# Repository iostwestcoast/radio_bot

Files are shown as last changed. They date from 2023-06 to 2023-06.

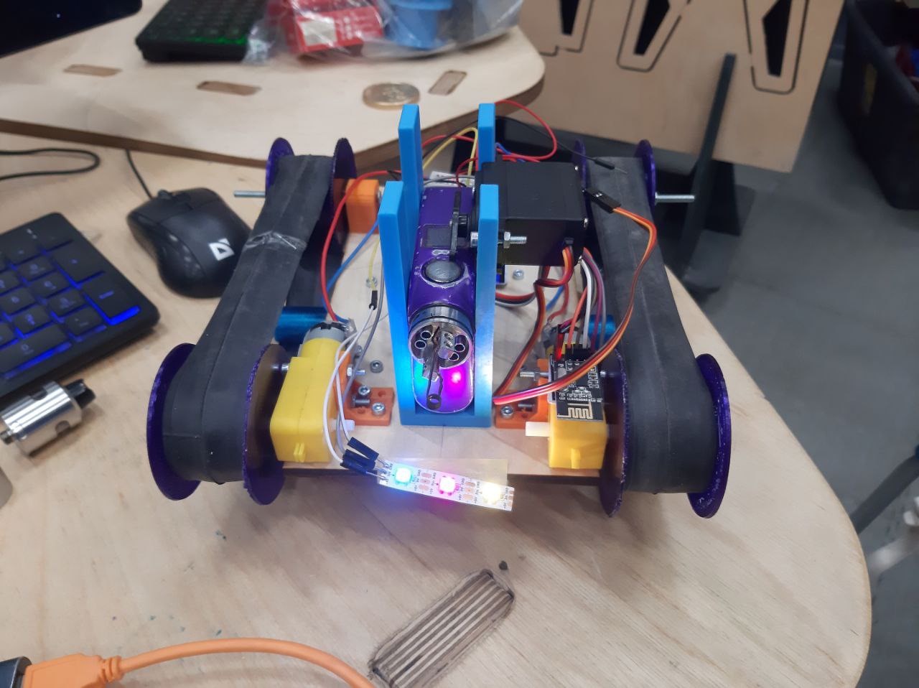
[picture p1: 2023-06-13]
Photos & Videoes/photo_2023-06-12_13-10-41.jpg

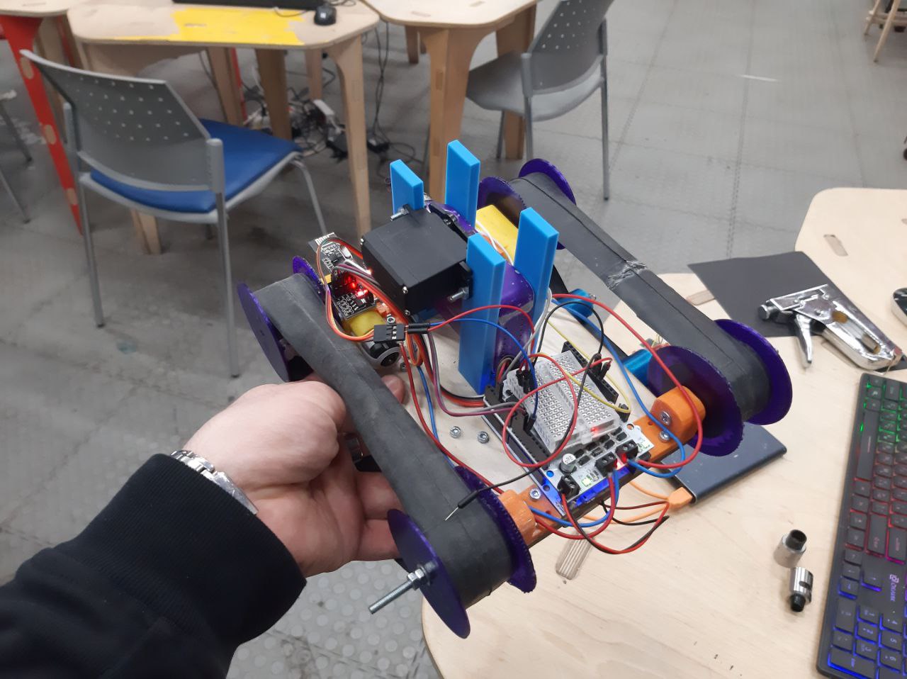
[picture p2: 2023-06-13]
Photos & Videoes/photo_2023-06-12_13-10-38.jpg

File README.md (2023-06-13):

# Radio Bot

Remote controlled bot based on an Arduino using a radio module

The final look of the bot:



The final view of the control panel:



https://github.com/iostwestcoast/radio_bot/assets/114690482/ab062ac3-bc5f-469a-a076-65d38420400c

Сomponents:

- NRF

- NRF+

- Motor Shield

- Arduino Leonardo/Amperka Iskra Neo

- Arduino Pro Micro

- x2 18650

- x2 DC motor

- x2 joystick

- RGB LED strip

- potentiometer

- x2 bradboard

- powerbank

- vape mod

- servo 360

The bot was created to pass a certain obstacle course and unfortunately for technical reasons did not meet expectations

In the end, 1/4 of the obstacle was passed and it took 9.45 minutes to complete the entire course



1. Control panel code:
```C++
#include <SPI.h>
#include <nRF24L01.h>
#include <RF24.h>

RF24 radio(8, 10);
int data[3];

#define PIN_VRX A2
#define PIN_VRY A3

void setup() {
  Serial.begin(9600);

  radio.begin();
  radio.setChannel(1);
  radio.setDataRate(RF24_1MBPS);
  radio.setPALevel(RF24_PA_HIGH);
  radio.openWritingPipe(0x2234567890LL);
  radio.stopListening();

  pinMode(A1, INPUT);
}

void loop() {
  int potval = analogRead(A1);

  radio.write(&data, sizeof(data));
  delay(50);

  Serial.println(potval);
     
  int valX = analogRead(PIN_VRX);
  int valY = analogRead(PIN_VRY);

  Serial.print("X = ");
  Serial.println(analogRead(PIN_VRX));

  Serial.print("Y = ");
  Serial.println(analogRead(PIN_VRY));

  data[0] = potval;
  data[1] = valX;
  data[2] = valY;
}
```

2. Bot code:
```C++
#include <SPI.h>
#include <nRF24L01.h>
#include <RF24.h>
#include <Servo.h>

Servo servo;

#define servoPin 11
int data[3];

RF24 radio(9, 10);

#define SPEED_1      5 
#define DIR_1        4
 
#define SPEED_2      6
#define DIR_2        7

#define LED_PIN 3
#define LED_NUM 3
#include "FastLED.h"
CRGB leds[LED_NUM];
byte counter;

void setup(){
  Serial.begin(9600);

  radio.begin();
  radio.setChannel(1);
  radio.setDataRate(RF24_1MBPS);
  radio.setPALevel(RF24_PA_HIGH);
  radio.openReadingPipe(0, 0x2234567890LL);
  radio.startListening();

  servo.attach(servoPin);

  for (int i = 4; i < 8; i++) {     
  pinMode(i, OUTPUT);

  FastLED.addLeds<WS2812, LED_PIN, GRB>(leds, LED_NUM);
  FastLED.setBrightness(200);
  }
}

void loop(){
  if (radio.available()){
    radio.read(&data, sizeof(data));
    Serial.println(String(data[0]) + "; " + String(data[1]) + "; " + String(data[2]));
  
  int potVal = data[0];
  servo.write(map(potVal, 0, 1023, 0, 180));

  delay(50);
  
  int valX = data[1];
  int valY = data[2];

  if (valX < 112) {
   digitalWrite(DIR_1, LOW);
   analogWrite(SPEED_1, 255);

   digitalWrite(DIR_2, HIGH);
   analogWrite(SPEED_2, 255);
  }
  else if (valX > 912) {
   digitalWrite(DIR_1, HIGH);
   analogWrite(SPEED_1, 255);

   digitalWrite(DIR_2, LOW);
   analogWrite(SPEED_2, 255);
  }
  else if (valY < 112) {
   digitalWrite(DIR_1, LOW);
   analogWrite(SPEED_1, 255);

   digitalWrite(DIR_2, LOW);
   analogWrite(SPEED_2, 255);
  }
  else if (valY > 912) {
   digitalWrite(DIR_1, HIGH);
   analogWrite(SPEED_1, 255);

   digitalWrite(DIR_2, HIGH);
   analogWrite(SPEED_2, 255);
  }
  
  else if (112 < valX < 912){
   digitalWrite(DIR_1, HIGH);
   analogWrite(SPEED_1, 0);

   digitalWrite(DIR_2, HIGH);
   analogWrite(SPEED_2, 0);
  }
  else if (112 < valY < 912){
   digitalWrite(DIR_1, HIGH);
   analogWrite(SPEED_1, 0);

   digitalWrite(DIR_2, HIGH);
   analogWrite(SPEED_2, 0);
  }
  }

  for (int i = 0; i < LED_NUM; i++) {
    leds[i].setHue(counter + i * 255 / LED_NUM);
  }
  counter++;
  FastLED.show();
}
```

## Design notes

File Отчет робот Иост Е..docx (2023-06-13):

МИНИСТЕРСТВО ОБРАЗОВАНИЯ И НАУКИ РОССИЙСКОЙ ФЕДЕРАЦИИ

ФЕДЕРАЛЬНОЕ ГОСУДАРСТВЕННОЕ АВТОНОМНОЕ УЧРЕЖДЕНИЕ ВЫСШЕГО ОБРАЗОВАНИЯ

«Национальный исследовательский технологический

университет «МИСиС»

ИНСТИТУТ ЭКОТЕХНОЛОГИЙ И ИНЖИНИРИНГА

КАФЕДРА МЕТАЛЛОВЕДЕНИЕ ЦВЕТНЫХ МЕТАЛЛОВ

НАПРАВЛЕНИЕ 15.04.02 Технологические машины и оборудование

Практика цифрового производства

на тему: “Робот на радиоуправлении”

Студент: Иост Е.С.

Группа: МТМО-22-3

Проверил: Тавитов А.Г.

Москва 2023

Введение

Цель проекта: построить робота без колес с дистанционным управлением для прохождения полосы препятствий.

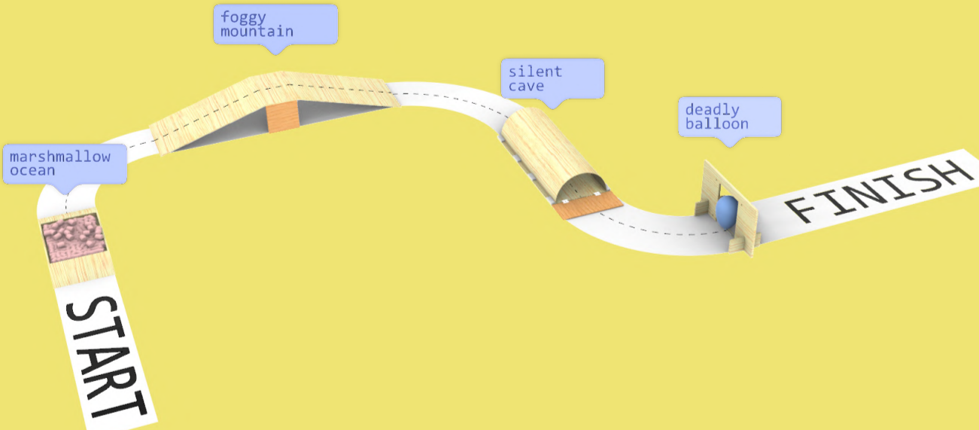
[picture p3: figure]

Рисунок 1 – Полоса препятствий

Компоненты, которые использовались в данном проекте:

- NRF

- NRF+

- Motor Shield

- Arduino Leonardo/Amperka Iskra Neo

- Arduino Pro Micro

- x2 18650

- x2 DC motor

- x2 joystick

- RGB LED strip

- potentiometer

- x2 bradboard

- powerbank

- vape mod

- servo 360

Скетчинг, эскизирование

Для начала работы было принято решение заскетчить все возможные варианты рабочих механизмов и расположения компонентов. Были сняты все размеры основных компонентов и важных узлов.

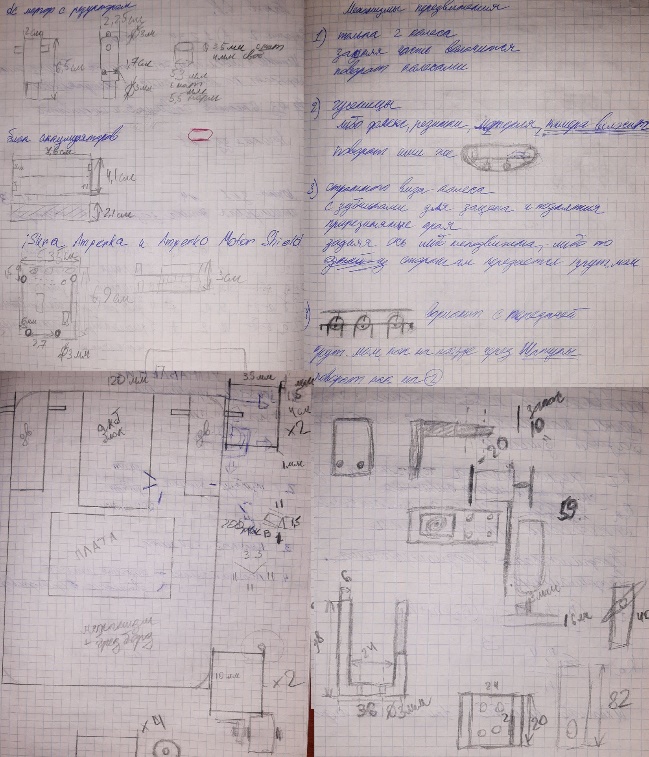
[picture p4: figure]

Рисунок 2 – Эскизы

По итогу было принято решение делать бота на гусеницах на прямоугольной платформе.

Моделирование и изготовление компонентов

Моделирование проводилось в программах CorelDRAW и SolidWorks. Компоненты изготавливались на 3D FFF принтере и лазерном ЧПУ станке.

Так как было принято решение делать бота на гусеницах необходимо сделать по 4 валка с каждой стороны. Основные ведущие приводные крепятся на валы моторов, вспомогательные служат для создания натяжения и трапециевидной формы гусеницы, а второстепенные такие же как основные только с круглым посадочным отверстием под болт.

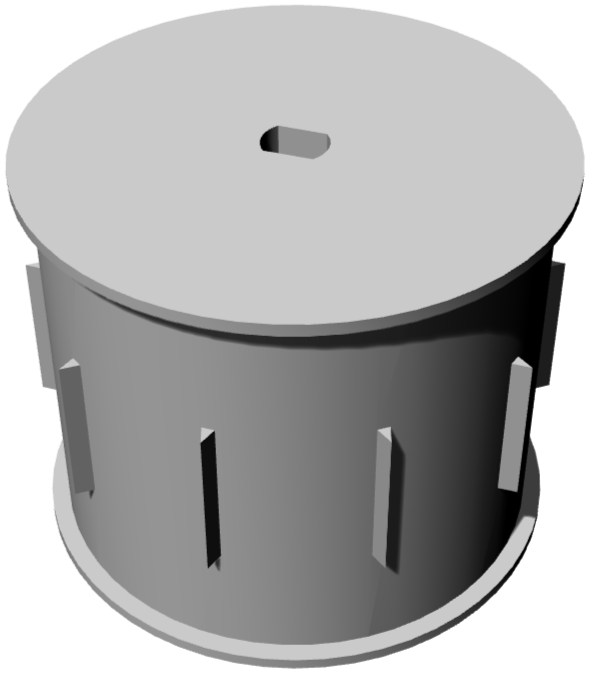
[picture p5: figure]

Рисунок 3 – 1 вариант модели основного валка

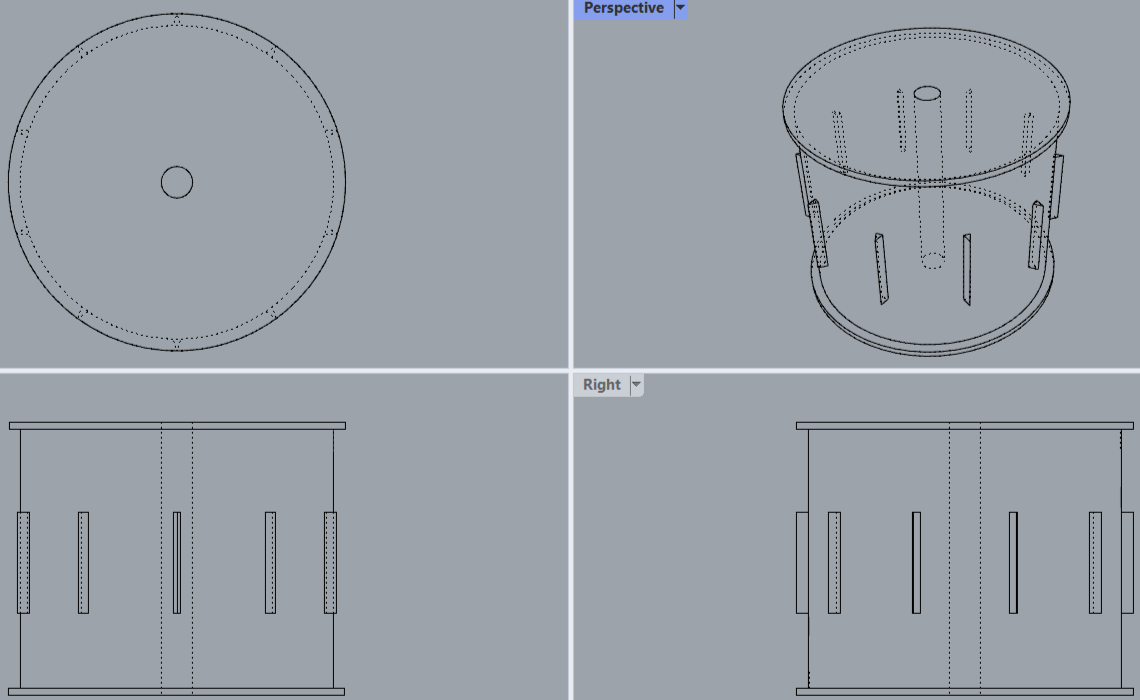
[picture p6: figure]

Рисунок 4 – 1 вариант модели второстепенного валка

Диаметр вала 40 мм, выступ 1 мм, гребенка 1 в высоту и 10 мм в длину, ширина 35 мм. Отверстие на основном вале по размерам выходного вала с мотора 3.5мм в высоту выреза и 5.5 мм по диаметру, на второстепенном 4 мм.

Далее по ходу сборки и тестирования аппарата выяснилось, что высота выступа в 1 мм слишком мала и гусеница постоянно соскакивала при передвижении. Было принято решение переделать модель и изготовить по-новому валки. Размер выступа в этот раз был изменен на 10 мм.

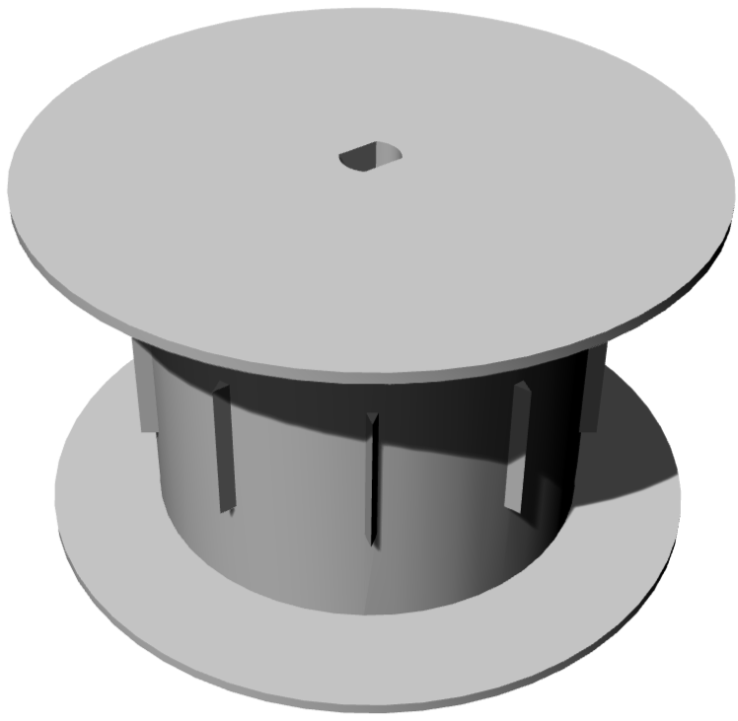
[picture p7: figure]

Рисунок 5 – 2 вариант модели основного валка

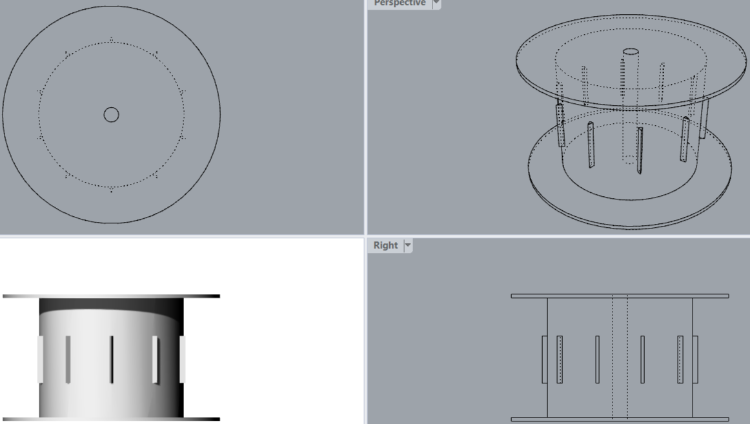
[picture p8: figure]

Рисунок 6 – 2 вариант модели второстепенного валка

Рисунок 7 – Модель вспомогательного валка

Далее необходимо было произвести кронштейны крепления моторов и валов. По заранее снятым размерам с компонентов были сделаны модели и произведена печать на принтере.

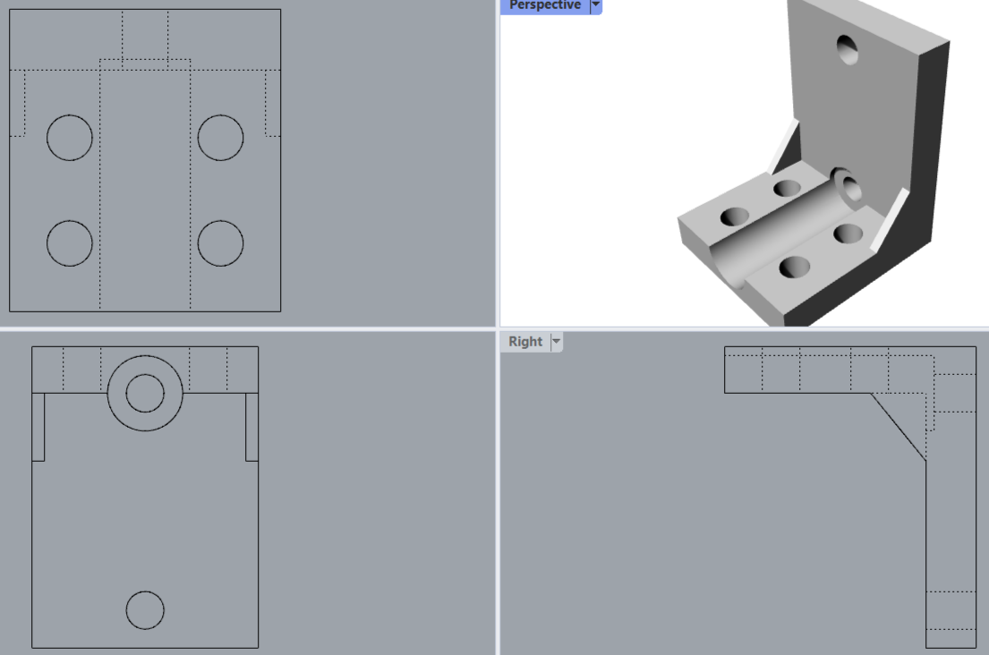
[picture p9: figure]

Рисунок 8 – Кронштейн крепления мотора

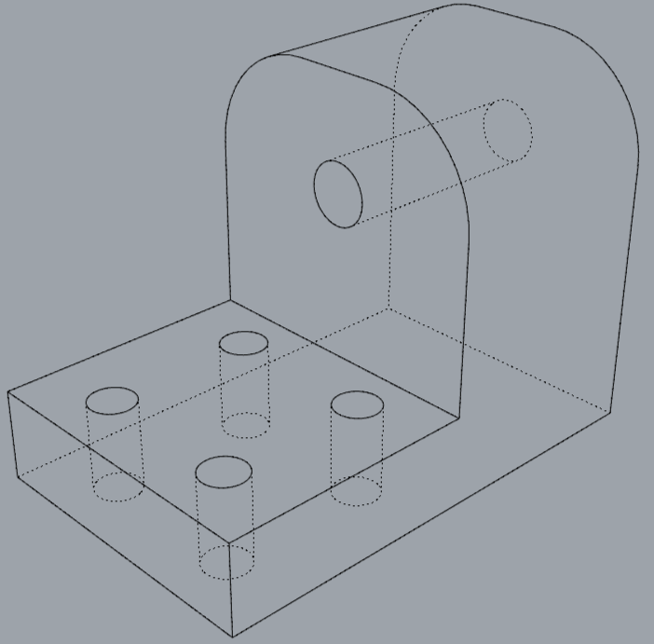
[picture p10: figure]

Рисунок 9 – Кронштейн крепления второстепенных валов

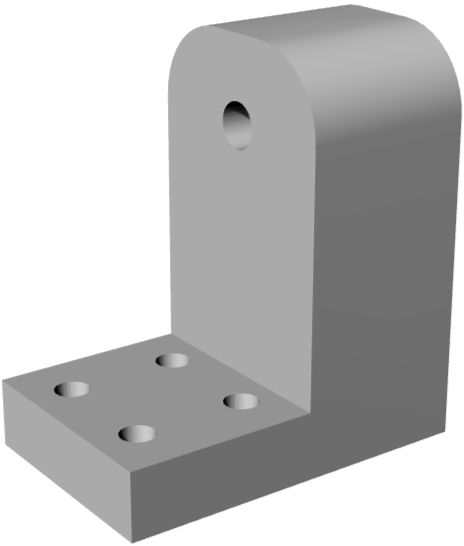
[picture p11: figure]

Рисунок 10 – Кронштейн крепления вспомогательных валов

Так как на полосе препятствий есть обязательное испытание – это лопнуть шарик и желательно это сделать интересным способом, было принято решение использовать vape mod для этого. Для него тоже необходимо сделать крепление.

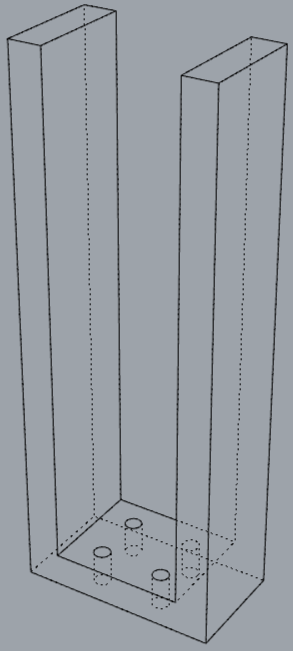
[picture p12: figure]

Рисунок 11 – Кронштейн крепления мода

Основная платформа вырезалась на лазерном станке из фанеры 6 мм, размерами 12х18 см.

Сборка компонентов

Для начала расположение компонентов размечалось на основной платформе. Далее из сложностей было, что 3D печать пластиком не идеальная технология и после печати необходимо дорабатывать детали, так нужно было отрывать поддержки, обрабатывать поверхности и рассверливать отверстия под нужные диаметры. Сборка кронштейном производилась с применением болтов М3, а в качестве осей вращения для валов было принято решение взять М4. Также для лучшего вращения валов использовались шайбы.

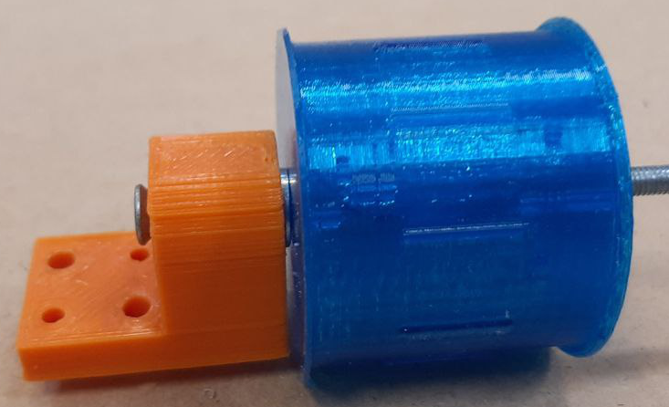
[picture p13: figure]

Рисунок 12 – Вал с кронштейном в сборе

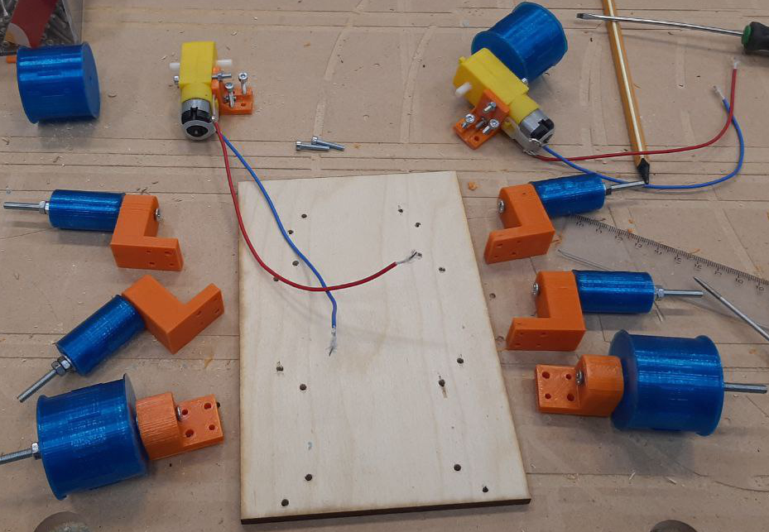
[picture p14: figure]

Рисунок 13 – Сборка готовых узлов

Рисунок 14 – Готовая сборка первичных компонентов

После долгого принятия решения по поводу изготовления гусениц, за основу была взята велосипедная камера. Она была разрезана на лоскуты шириной 3.5 см по ширине валов. Длина измерялась практическим методом. Для скрепления двух концов использовался степлер и клей.

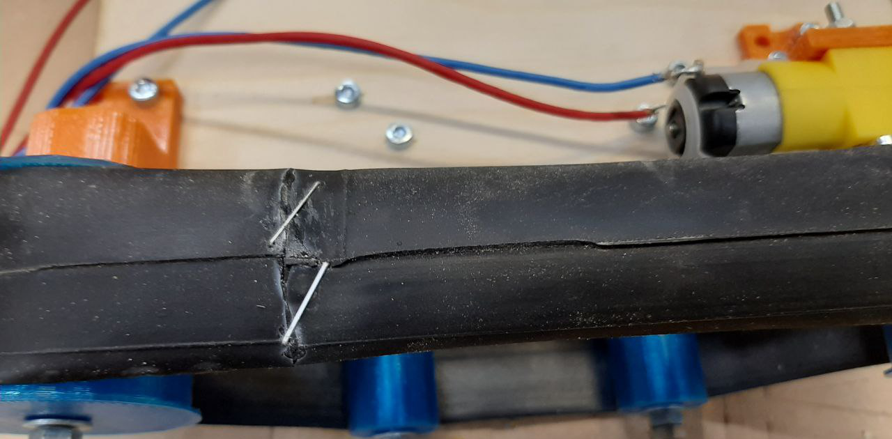
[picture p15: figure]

Рисунок 15 – Стык гусеницы

Для дальнейшей работы сначала необходимо было произвести тестовую сборку электроники без радио модуля. Все компоненты ввода были подключены на прямую к плате. Производилась отладка работы двигательных систем и работы сервопривода с написанием кода для платы управления Arduino Leonardo.

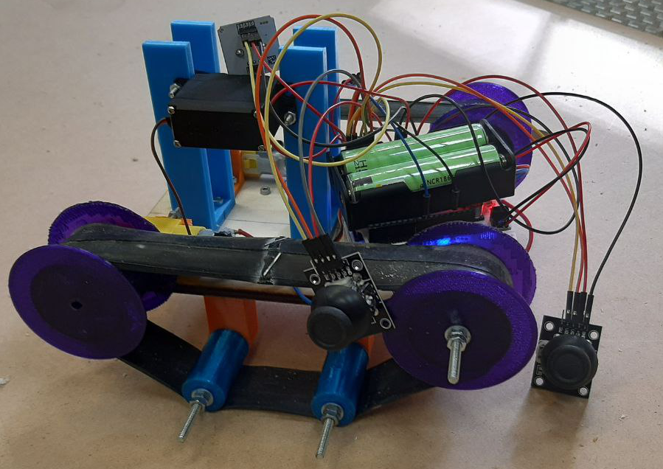
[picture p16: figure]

Рисунок 16 – Предварительная сборка электроники

После предварительной отладки работы приступили к подключению радио модулей и изготовлению мульта управления. Для простоты и меньшей траты ресурсов, было принято решение производить сборку и взять за основу пульта длинный bradboard. Компоненты крепились на саму основу, или на стяжки, или на двухсторонний скотч. Выбиралось эргономичное расположение и производился кабель менеджмент.

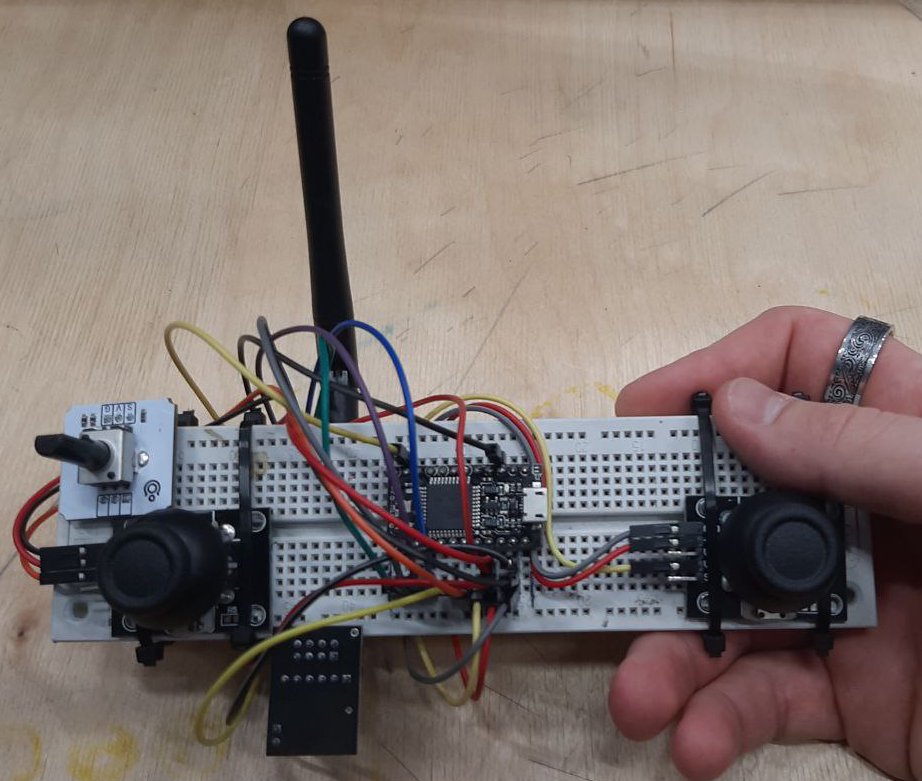
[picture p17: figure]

Рисунок 17 – Готовый пульт управления

Далее производилась конечная сборка компонентов робота. Элементы электроники крепились на двухсторонний скотч к основе, светодиодная лента на термоклей в передней части бота. Аккумуляторный блок закрепили под основной платформой. За механизм для лопанья шарика был взят vape mod. На его дрипку была накручена спираль вытянутой формы, на кронштейнах закреплен сервопривод, который нажимает на кнопку мода при считывании сигнала с потенциометра, спираль при нажатии начинает разогреваться.

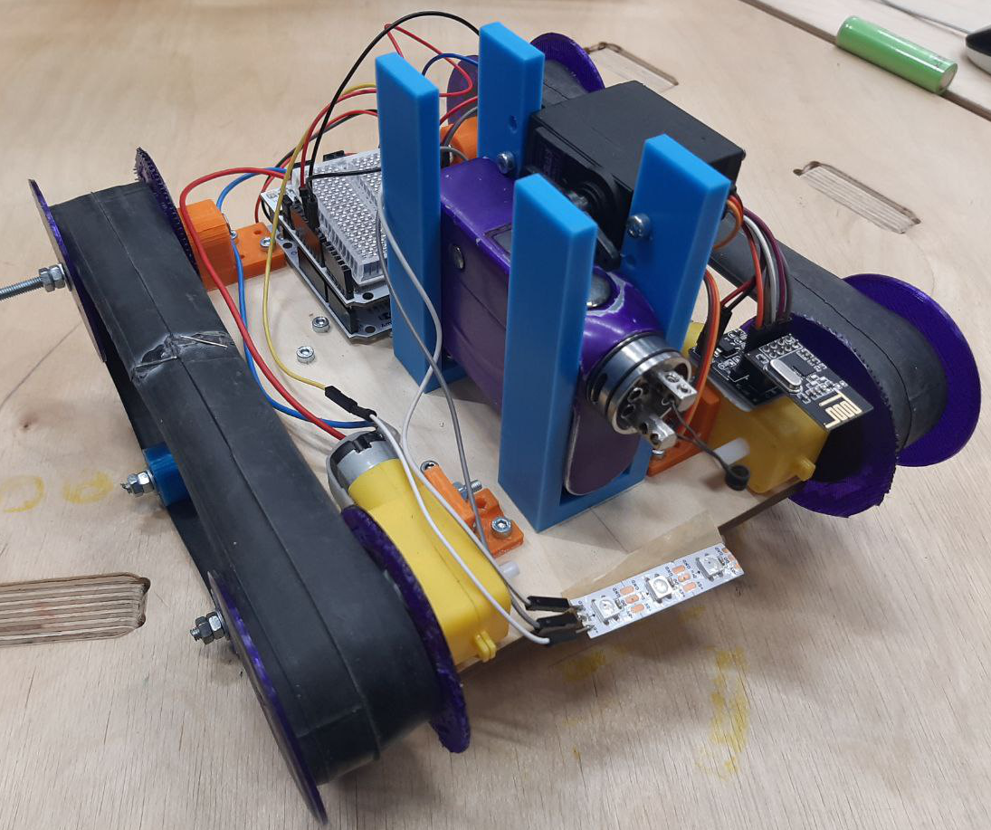
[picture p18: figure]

Рисунок 18 – Готовый бот

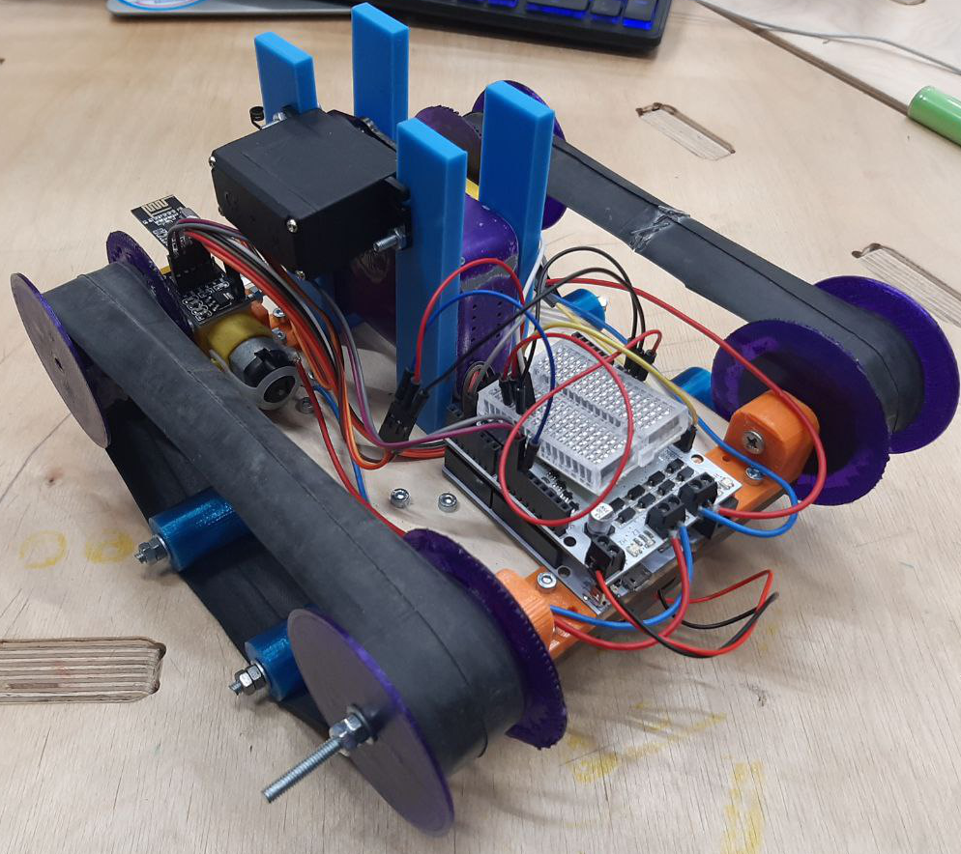
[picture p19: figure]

Рисунок 19 – Готовый бот

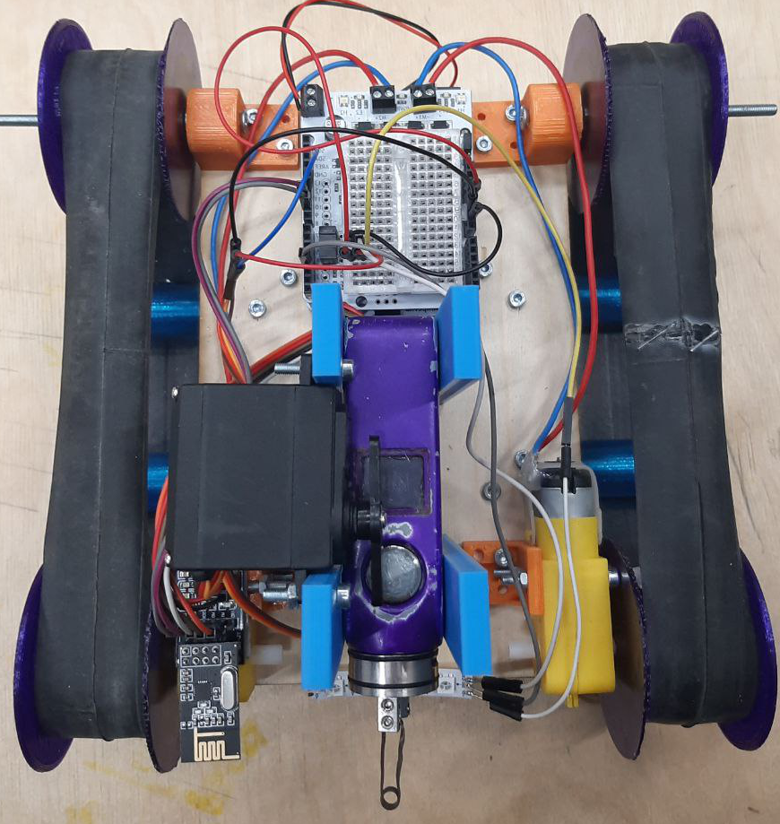
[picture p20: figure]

Рисунок 20 – Готовый бот

Схемы подключения электроники

Вся электроника подключалась либо на прямую к плате, либо с использованием платы bradboard. Управляющая плата на боте Arduino Leonardo/Amperka Iskra Neo с Motor Shield, а на пульте управления Arduino Pro Micro. Связь настроена через радио модули NRF и NRF+. Далее будут представлены схемы подключения основных узлов электроники и готовых агрегатов.

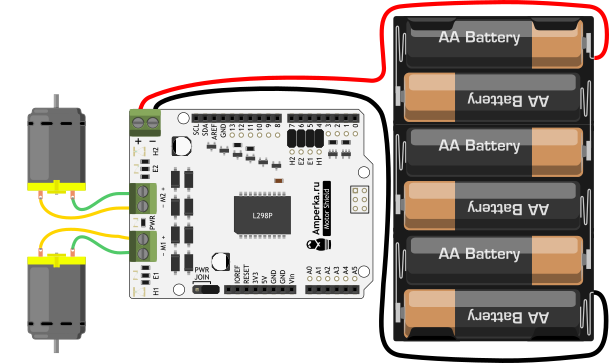
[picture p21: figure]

Рисунок 21 – Схема подключения аккумуляторного блока и моторов к Motor Shield

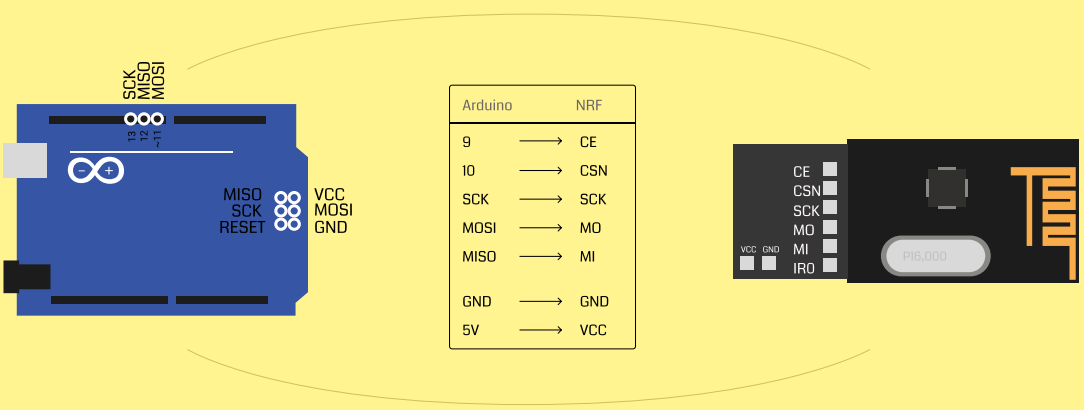
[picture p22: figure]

Рисунок 22 – Схема подключения радио модуля к Arduino Leonardo

Рисунок 23 – Схема подключения радио модуля к Arduino Pro Micro

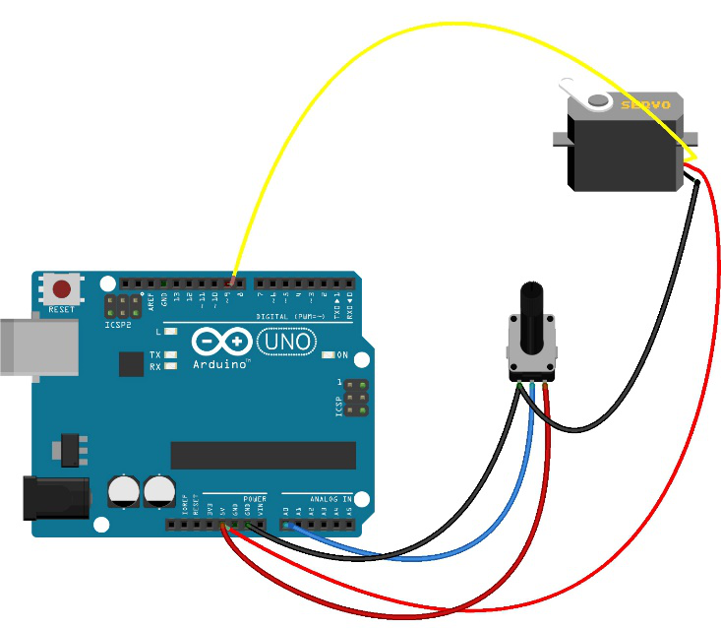
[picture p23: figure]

Рисунок 24 – Схема подключения потенциометра с сервоприводом

Код Arduino

Написание кода проводилось в программе Arduino IDE. Необходимо было установить дополнительные библиотеки для управления сервоприводом, светодиодной лентой и радио модулями. На пульте управления считываются входные данные с устройств ввода, создается массив данных и передается на приемник на боте, там из массива достаются данные и распределяются на конкретные агрегаты.

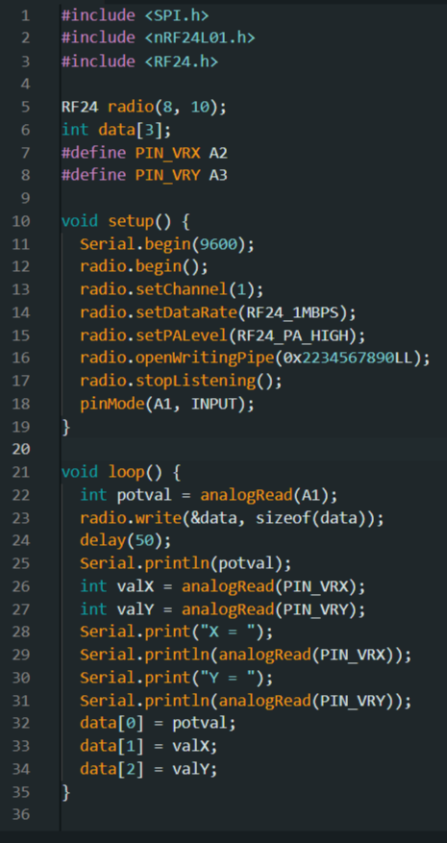
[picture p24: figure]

Рисунок 25 – Код для пульта управления

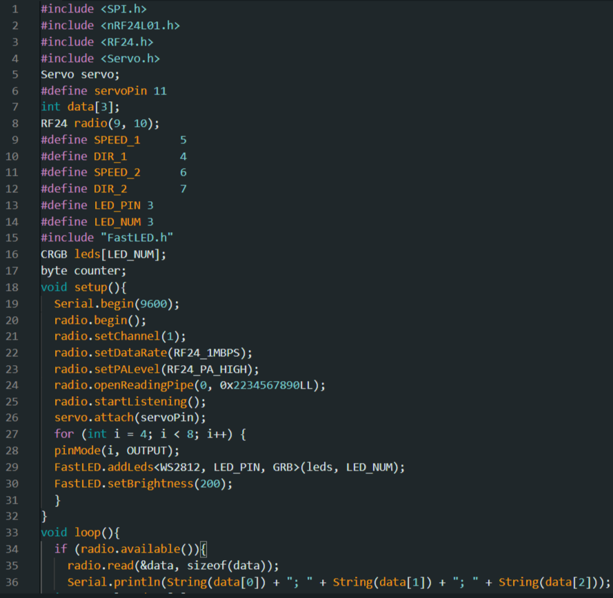
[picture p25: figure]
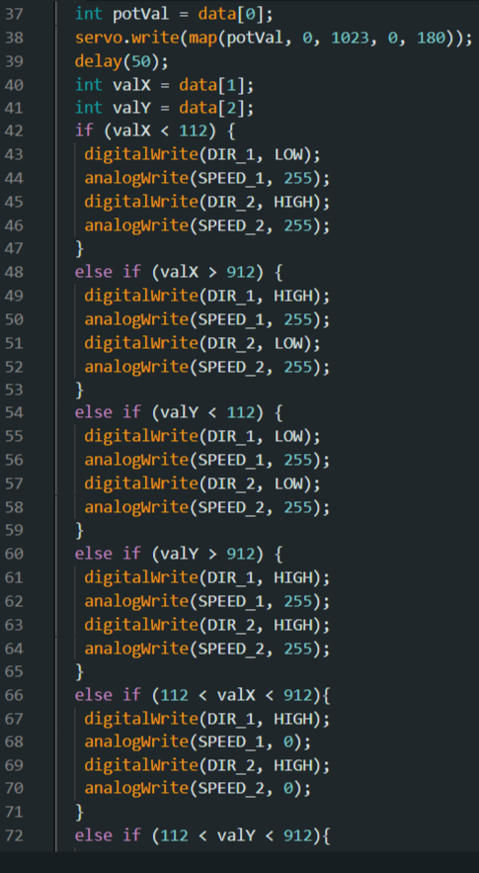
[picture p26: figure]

Рисунок 26 – Код для бота

Заключение

По итогу проделанной работы над проектом была достигнута поставленная цель. Были смоделированный и изготовлены компоненты и детали, произведена сборка и отладка робота и пульта управления, подлечены электронные компоненты и написан код для управления данными агрегатами.

К сожалению, по завершению прохождения препятствий выяснилось, что конструктивно у робота получился большой вес, в связи с этим моторам не хватало крутящего момента, для передвижения под углом, из-за слабой натяжки гусеницы, не получалось преодолеть ступени для подъема, всё упиралось в мощность моторов. Также неисправность сервопривода привело плохой работе механизма нажатия кнопки. На полосе было пройдено 1/4 препятствий и было затрачено 9.45 минут. В дальнейших проектах будут учтены выводы.

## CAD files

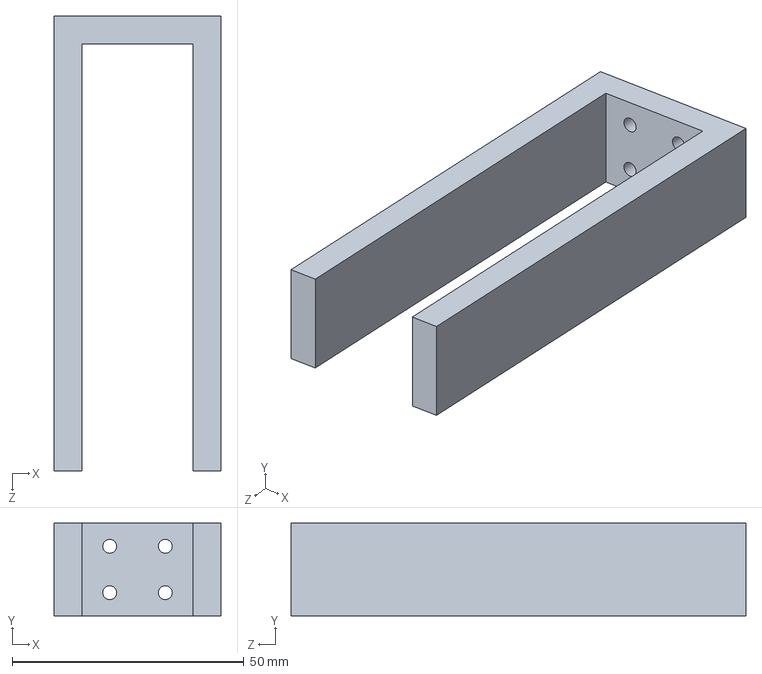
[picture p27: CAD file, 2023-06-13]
CAD & STL models/holder/mod_holder.SLDPRT
36.0 x 20.0 x 98.0 mm

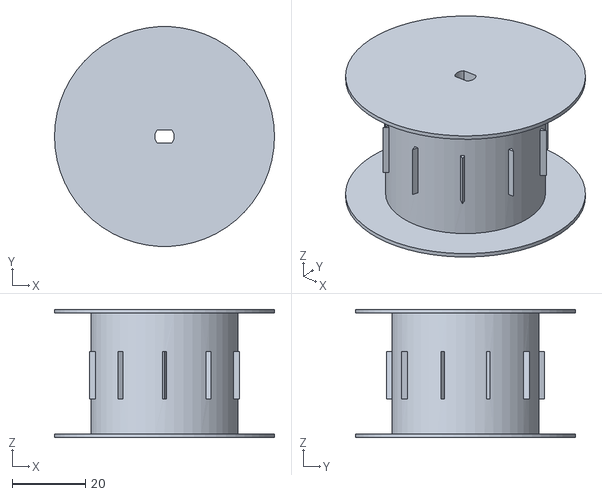
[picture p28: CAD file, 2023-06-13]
CAD & STL models/wheels/ведущее v2.STL
60.0 x 59.9 x 35.0

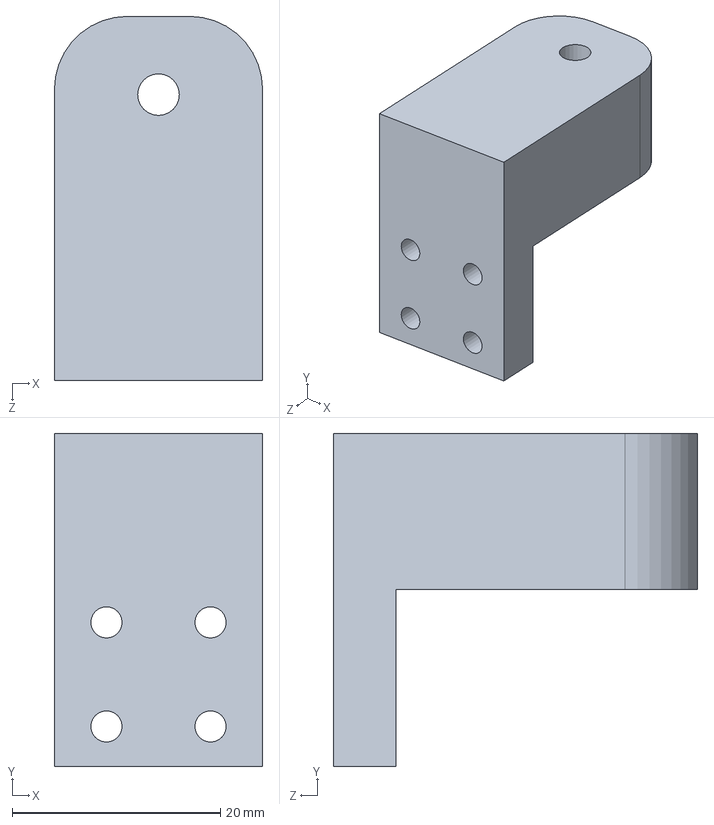
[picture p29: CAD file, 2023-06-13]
CAD & STL models/holder/helpwheels_holder 4.SLDPRT
20.0 x 32.0 x 35.0 mm

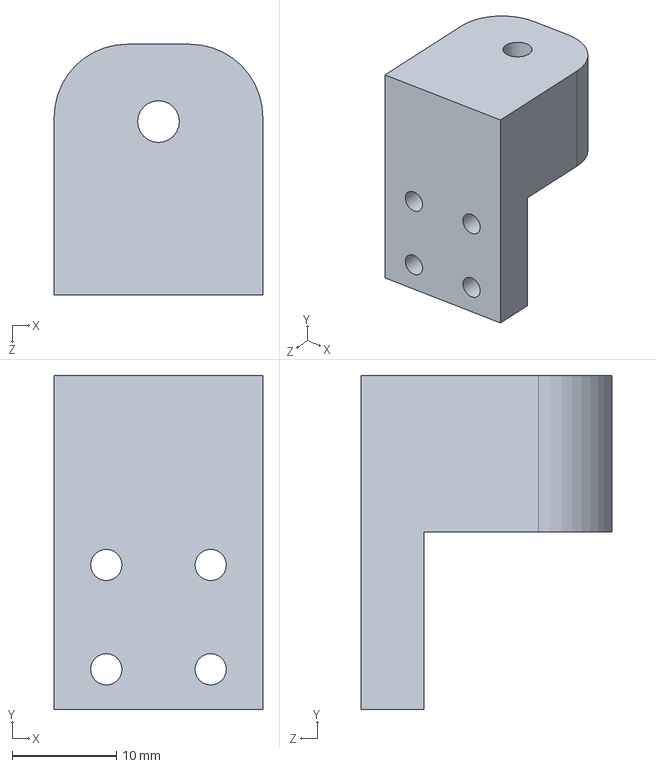
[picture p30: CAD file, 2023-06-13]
CAD & STL models/holder/wheels_holder 2.SLDPRT
20.0 x 32.0 x 24.0 mm

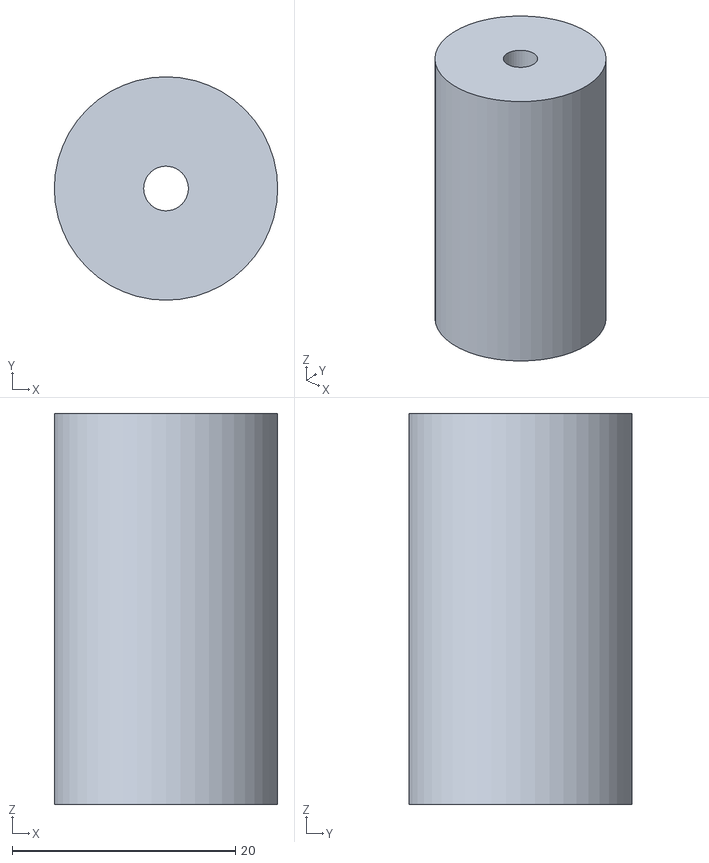
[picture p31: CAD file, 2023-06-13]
CAD & STL models/wheels/вспомогательное 4.STL
20.0 x 20.0 x 35.0

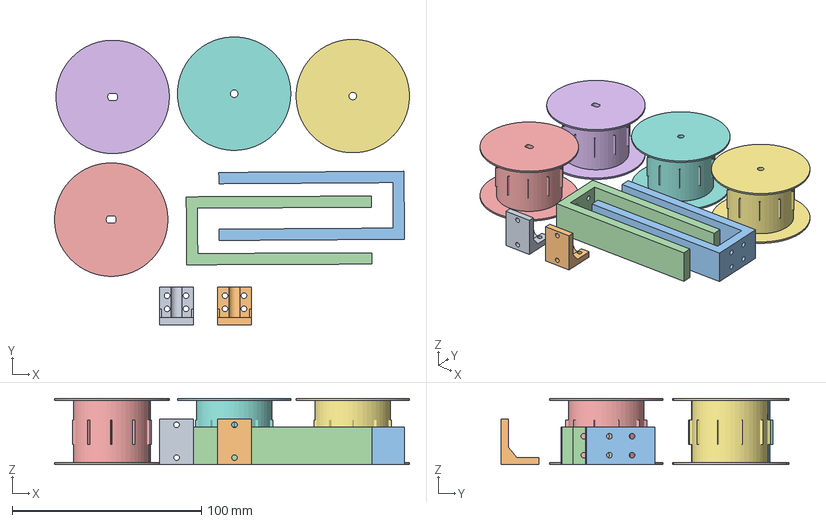
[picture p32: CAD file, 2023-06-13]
CAD & STL models/holder/2.3mf
187.7 x 152.3 x 35.0 mm
mototor_holder 2.stl
mod_holder.STL
ведущее v2.STL
второстепенное v2.STL

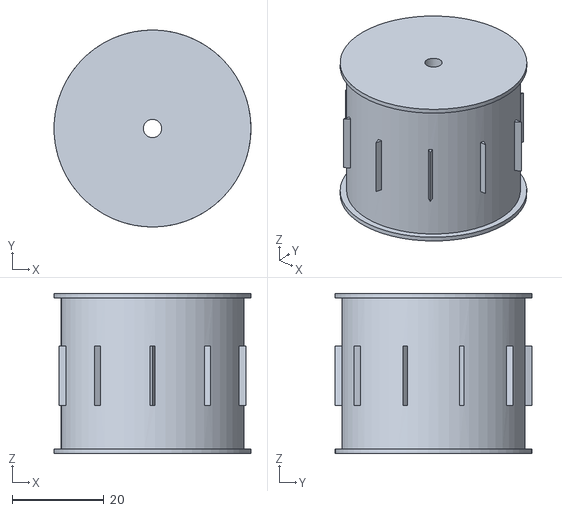
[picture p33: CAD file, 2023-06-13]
CAD & STL models/wheels/второстепенное 2.STL
43.0 x 43.0 x 35.0

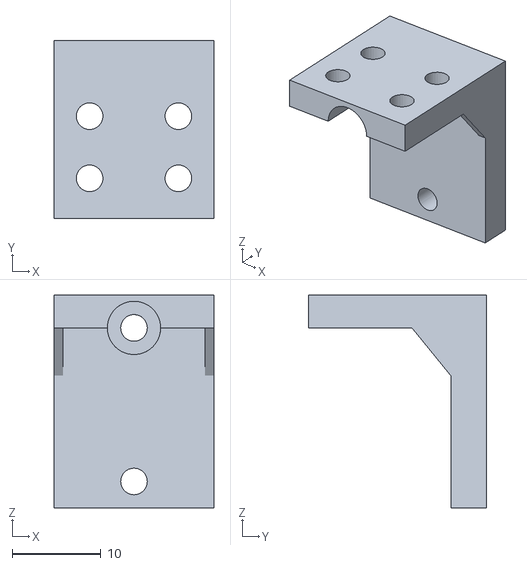
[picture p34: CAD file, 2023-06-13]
CAD & STL models/holder/mototor_holder 2.stl
18.0 x 20.0 x 24.0

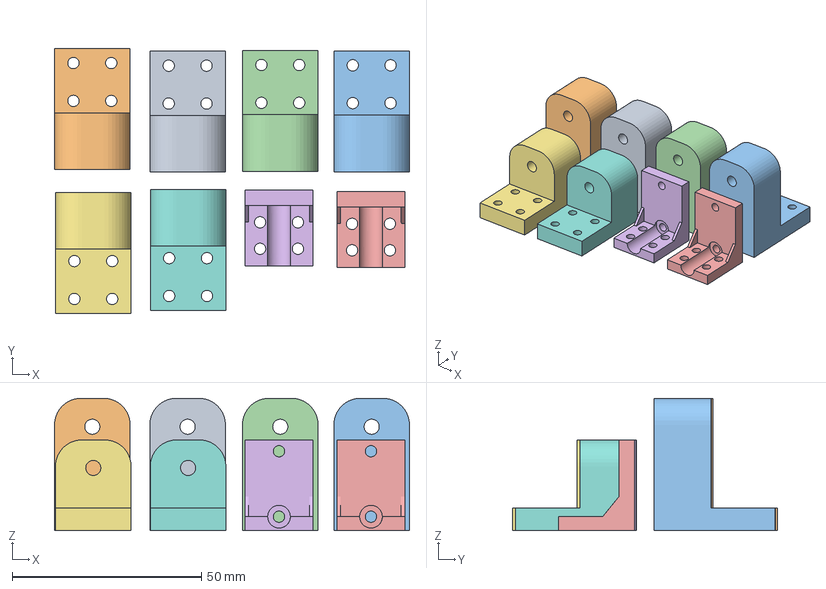
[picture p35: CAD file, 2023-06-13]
CAD & STL models/holder/all_holders_iost.3mf
93.8 x 70.0 x 35.0 mm
helpwheels_holder 4.STL x 2
mototor_holder 2.stl
wheels_holder 2.STL

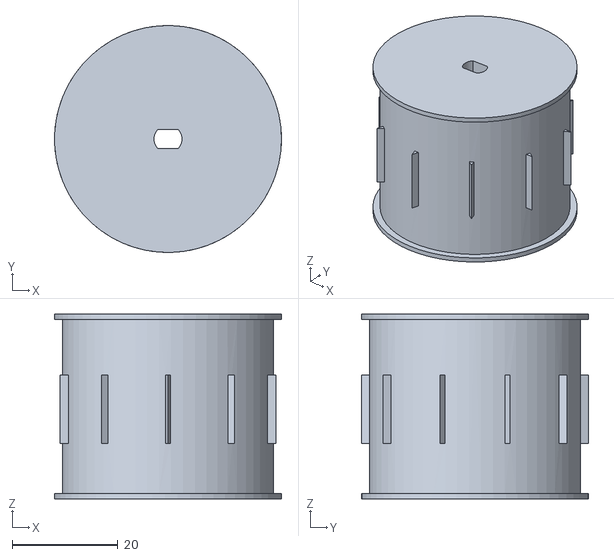
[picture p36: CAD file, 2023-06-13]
CAD & STL models/wheels/ведущее 2.STL
43.0 x 43.0 x 35.0

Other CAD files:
CAD & STL models/wheels/второстепенное.SLDPRT
CAD & STL models/wheels/вспомогательное.SLDPRT
CAD & STL models/wheels/ведущее.SLDPRT
CAD & STL models/wheels/второстепенное v2.STL
CAD & STL models/holder/helpwheels_holder 4.STL
CAD & STL models/holder/mod_holder.STL
CAD & STL models/holder/wheels_holder 2.STL
